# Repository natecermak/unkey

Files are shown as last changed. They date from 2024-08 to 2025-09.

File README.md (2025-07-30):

# Acoustic Underwater Text-based Communication Device (Name TBD)

## Purpose/Motivation
Divers often need to communicate with one another or with a dive boat, but typically can only communicate when in visual range of each other. A simple means to communicate with a bandwidth of text messaging (~40 wpm) over distances of several hundred meters could potentially save lives when if other divers or the dive boat can be made aware of and respond to unexpected conditions/situations.

## Communication scheme overview
Acoustic communication is basically the only feasible scheme underwater, and hence has been the standard for underwater communication since at least the early 1900s. Electromagnetic signals penetrate very poorly underwater, so convential means of communication (cellular communication, radio/walkie-talkies, bluetooth, wifi) are not feasible. Optical signaling is sometimes feasible (e.g. with flashlights), but relies on line of sight and good water clarity, and has limited range due to scattering and absorption underwater. However, if one has ever heard dolphins or whales underwater, they can attest to the immense distances these signals can travel, greatly exceeding the distance one can see underwater.

Underwater environments (a) add a lot of noise and (b) distort signals due to reflections.

Here, we use a **FM/AM/OFDM** scheme to send bits.

## Subsystems:

### Keyboard
To get around difficulties with mechanical keys, we chose to use magnetic sensors and a magnet-bearing stylus. Underwater, mechanical keys have several failure modes:
 - They can break in such a way that allows water into the device, and
 - As one goes underwater, pressure increases, which eventually can press keys on its own, at which point buttons are stuck in the 'pressed' state, and basically useless.
We chose to use omnipolar Hall-effect switches, which have a digital output that changes from high to low when the magnetic flux through the device increases beyond some threshold. We rapidly read out every key's on/off state using an array of daisy-chained shift registers, an approach commonly used in other keyboards. When the user brings the magnet-tipped stylus near a sensor "key", the microcontroller can read the change in the Hall-effect switch output.

Users typically prefer some tactile feedback when they hit a key, and this system doesn't naturally provide that. As such, we experimented with adding a soft (low coercivity) magnetic material (1-2mm mild steel ball bearings) above the Hall-effect sensor, to provide a small pull-in magnetic force when the stylus is brought close to the key. This provides tacticle sensation to the user that they have actually touched a key. It's essential that this material is magnetizable so that it attracts the stylus, but also that it cannot develop a permanent magnetic moment. If it were to develop a permanent magnetic moment, it would turn the Hall-effect sensor on all the time and the key would be stuck "on".

Keyboard layout:
---------- Default, no modifier -------
1   2   3   4   5   6   7   8   9   0
q   w   e   r   t   y   u   i   o   p
  a   s   d   f   g   h   j   k   l   DEL
CAP z   x   c   v   b   n   m   ?   BCK
SYM      SPACESPACESPACESP   ,   .    RET
(plus 6 arrow keys, SEND)

---------- SYM modifier ---------------
!   @   #   $   %   ^   &   *   (   )
`   ~   -   _   =   +   :   ;   '   "
  [   ]   {   }   |   \   /   <   >   DEL
CAP z   x   c   v   b   n   m   ?   BCK
SYM      SPACESPACESPACESP   ,   .    RET

key count is:
    row 1: 10 keys
    row 2: 10 keys
    row 3: 10 keys
    row 4: 10 keys
    row 5: 5 keys
    off-grid: 6 arrow keys, 1 SEND key
Total: 52 keys

Non-character keys: 6 arrow keys, SEND, BCK, DEL, CAP, SYM

Future work could use open-drain hall-effect sensors in a grid to give more precise hit-boxes (e.g. a 2x2 grid of AH1925-HK4-7, wired in parallel, for each key). However, this would be significantly more expensive, as it would require roughly 4x as many switches.

### Microcontroller
We use a Teensy 4.1 microcontroller due to ease of development. Essential features this microcontroller provides are:
 - rapid (~100 ksps) ADC readout via DMA
 - SPI peripheral for driving a TFT LCD scree
n - DMA-compatible SPI peripheral for driving a DAC
 - I2C peripheral for controlling an external switch matrix
However, many other microcontrollers would likely work fine for this system.

### Battery
We use a rechargeable lithium ion battery, which provides a nominal 3.7V input.

### Transducer
We use a 45mm x 45mm x 1.4mm square piezo plate from Steminc (SMPL45W45T14111) as a transducer. This piezo is spec'd as having a capacitance of 5.4nF +- 20%. It's made from material SM111, which has a piezo d33 constant of 320e-12 C/N.

We made some measurements of the impedance at various frequencies:
    - Frequency   Real      Imaginary     (Capacitance, Q)
    -  0.1 kHz:   570    -  103.5k imag   (15.3nF, Q=182)
    -  1.0 kHz:    45    -   10.42k imag  (15.3nF, Q=236)
    - 10.0 kHz:     2.9  -    1.03k imag  (15.4nF, Q=356)
    - 40.0 kHz:     2.25 -       63 imag  (63.0nF, Q=28)
    -100.0 kHz:    -0.09 -      132 imag  (12nF,   Q=1350)

Overall, this seems pretty discrepant with their claim of 5.4nF. Given two parallel plates of this size, separated by 1.4mm, and a dielectric constant of 1400 (also from the [SM111 materials page](http://www.steminc.com/piezo/PZ_property.asp)), the calculated capacitance should be 17.9nF, closer to our measured value than their spec.

We also purchased several other transducers to try out, but have not yet used/characterized ther others:
- SMD25T14F15111 - Piezo Ceramic Disc 25x1.4mm R 1.5 Mhz          1.9 nF
- SMD50T21F1000R - Piezo Electric Disc 50x2.1mm R 1 MHz           10 nF

### Transducer driver

### Transducer sensor
We use a charge amplifier circuit with a configurable gain.

### Sensor data processing
We use Goertzel filters to extract amplitude and phase at a fixed set of frequencies.

### Screen
TBD.

### Enclosure
TBD.

## Version history:
v1.2 PCB changes:
 - [X] switch from teensy 4.1 to t4 for space
 - [X] add battery monitor circuitry
 - [X] replicate LiIon charger circuit on it https://github.com/adafruit/Adafruit-USB-LiIon-LiPoly-Charger-PCB/tree/master
 - [X] switch shift registers to qfn
 - [X] redo keyboard layout
 - [X] add 40-pin ZIF connector for 3.2" TFT from buydisplay.com
 - [X] make all passives 0402 for consistency
 - [X] add explicit space for screen
 - [X] add explicit space for battery
 - [X] add explicit space for Qi charger coil + PCB
 - [X] pull LAT down on MCP4, or just wire it out -- cant leave it floating
 - [X] CE on 5V boost wont work! needs to be always enabled, and drive a switch
 - [X] figure out FMARK and RD on ZIF connector for display: tested with them floating and display still works, so non-essential

v1.3 pcb
 - [X] split board into two separate parts with explicit design for overall assembly. This is for two reasons:
    1. so that I can do single-sided assembly on both pieces, but then have some parts sticking up (keyboard) and some facing down (teensy/driver electronics)
    2. it makes the face of the screen flush with the face of the magnetic switches.
 - [X] fix TFT connector pin numbering (it's backwards from the connector)
 - [X] make an attempt at a BOM

---

## Firmware File Organization

```
firmware/
├── platformio.ini
├── include/                  # All header files
│   ├── battery.h
│   ├── chat_logic.h
│   ├── comm.h
│   ├── config.h              # Shared constants, types, UI/chat/layout settings
│   ├── display.h
│   ├── goertzel.h
│   ├── hardware_config.h     # Pin assignments and hardware setup
│   └── keyboard.h
├── src/                      # Main firmware source code
│   ├── battery.cpp
│   ├── chat_logic.cpp        # Message buffer, scrolling, state management
│   ├── comm.cpp              # Encode/decode bits, tx/rx state
│   ├── display.cpp           # Drawing chat, keyboard, cursor
│   ├── goertzel.cpp          # Frequency detection (demodulation)
│   ├── keyboard.cpp          # Polling, key states, modifiers, stylus interaction
│   └── main.cpp              # Entry point: setup(), loop(), high-level orchestration
├── test/                     # Unit test suites (organized by feature and file)
│   ├── receiving/
│   │   ├── test_adc_buffer_full_interrupt/
│   │   │   └── adc_buffer_full_interrupt.cpp
│   │   ├── test_decode_single_bit_from_adc_window/
│   │   │   └── decode_single_bit_from_adc_window.cpp
│   │   ├── test_deliver_message/
│   │   │   └── deliver_message.cpp
│   │   ├── test_get_bit_from_top_frequency/
│   │   │   └── get_bit_from_top_frequency.cpp
│   │   ├── test_parse_message/
│   │   │   └── parse_message.cpp
│   ├── transmitting/
│   │   └── test_packetize_message/
│   │       └── packetize_message.cpp
│   ├── mock_display.cpp
│   └── mock_display.h
```

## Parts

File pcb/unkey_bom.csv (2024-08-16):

# | Reference | Qty | Value | Footprint | DNP | Digikey PN | URL
1 | C1, C2, C3, C4, C5, C6, C7, C10, C11, C20, C22, C23, C24, C26, C27, C31 | 16 | 0.1u | Capacitor_SMD:C_0402_1005Metric |  | 1276-1043-1-ND | https://www.digikey.com/en/products/detail/samsung-electro-mechanics/CL05A104KA5NNNC/3886701
2 | C8, C9, C21, C25, C28, C29, C32 | 7 | 2.2u | Capacitor_SMD:C_0402_1005Metric |  | 445-9028-1-ND | https://www.digikey.com/en/products/detail/tdk-corporation/C1005X5R1V225K050BC/3648550
3 | C12 | 1 | 33n | Capacitor_SMD:C_0402_1005Metric
4 | C13 | 1 | 10n | Capacitor_SMD:C_0402_1005Metric
5 | C14 | 1 | 3.3n | Capacitor_SMD:C_0402_1005Metric
6 | C15 | 1 | 1n | Capacitor_SMD:C_0402_1005Metric
7 | C16 | 1 | 330p | Capacitor_SMD:C_0402_1005Metric
8 | C17 | 1 | 100p | Capacitor_SMD:C_0402_1005Metric
9 | C18 | 1 | 33p | Capacitor_SMD:C_0402_1005Metric
10 | C19 | 1 | 10p | Capacitor_SMD:C_0402_1005Metric
11 | D65, D66, D67 | 3 | LED | LED_SMD:LED_0603_1608Metric |  | APT1608CGCK | https://www.digikey.com/en/products/detail/kingbright/APT1608CGCK/1747514
12 | J1, J4, J7, J8, J11 | 5 | Conn_01x02_Pin | Connector_PinHeader_2.54mm:PinHeader_1x02_P2.54mm_Vertical
13 | J2, J3 | 2 | Conn_01x05_Pin | Connector_PinHeader_2.54mm:PinHeader_1x05_P2.54mm_Vertical
14 | J6 | 1 | Conn_01x40_Pin | Connector_FFC-FPC:Hirose_FH12-40S-0.5SH_1x40-1MP_P0.50mm_Horizontal |  | https://www.digikey.com/en/products/detail/hirose-electric-co-ltd/FH12A-40S-0-5SH-55/1110338 | https://www.digikey.com/en/products/detail/hirose-electric-co-ltd/FH12A-40S-0-5SH-55/1110338
15 | J12, J13, J14 | 3 | Conn_01x02_Pin | Connector_PinHeader_2.54mm:PinHeader_1x02_P2.54mm_Vertical | DNP
16 | PS1 | 1 | PDSE1-S3-D24-M | unkey-footprints:CONV_PDSE1-S3-D24-M |  | 102-PDSE1-S3-D24-M-ND | https://www.digikey.com/en/products/detail/cui-inc/PDSE1-S3-D24-M/20526618
17 | R1, R79 | 2 | 100 | Resistor_SMD:R_0402_1005Metric
18 | R2, R3, R9, R81, R82, R84 | 6 | 1k | Resistor_SMD:R_0402_1005Metric
19 | R4 | 1 | 0 | Resistor_SMD:R_0402_1005Metric
20 | R5 | 1 | 100M | Resistor_SMD:R_0402_1005Metric |  | HMC0402JT100MCT-ND | https://www.digikey.com/en/products/detail/stackpole-electronics-inc/HMC0402JT100M/2683706
21 | R6, R80 | 2 | 500 | Resistor_SMD:R_0402_1005Metric
22 | R10 | 1 | 18k | Resistor_SMD:R_0402_1005Metric
23 | R11, R68 | 2 | 10k | Resistor_SMD:R_0402_1005Metric
24 | R76, R78 | 2 | 100k | Resistor_SMD:R_0402_1005Metric
25 | R83 | 1 | 2k | Resistor_SMD:R_0402_1005Metric
26 | TH1 | 1 | 10k | Resistor_SMD:R_0402_1005Metric |  | 490-NCU15XH103F6SRCCT-ND | https://www.digikey.com/en/products/detail/murata-electronics/NCU15XH103F6SRC/10702829
27 | U1, U2, U3, U4, U5, U6, U7, U8, U9, U10, U11, U12, U13, U14, U15, U16, U17, U18, U19, U20, U21, U22, U23, U24, U25, U26, U27, U28, U29, U30, U31, U32, U33, U34, U35, U36, U37, U38, U39, U40, U41, U42, U43, U44, U46, U47, U48, U49, U50, U51, U52 | 51 | AH1912-W | Package_TO_SOT_SMD:SC-59 |  | AH1912-W-7DICT-ND | https://www.digikey.com/en/products/detail/diodes-incorporated/AH1912-W-7/10071170
28 | U45, U68, U69, U70 | 4 | AH1921-W-7 | Package_TO_SOT_SMD:SC-59 |  | AH1921-W-7DICT-ND | https://www.digikey.com/en/products/detail/diodes-incorporated/AH1921-W-7/9674238
29 | U53, U54, U55, U56, U57, U58, U59 | 7 | SN74LV165ARGYR | Package_DFN_QFN:Texas_RGY_R-PVQFN-N16_EP2.05x2.55mm |  | 296-13937-1-ND | https://www.digikey.com/en/products/detail/texas-instruments/SN74LV165ARGYR/521496
30 | U60 | 1 | MYRBP500080B21RE | unkey-footprints:MYRBP500080B21RE |  | 811-MYRBP500080B21RECT-ND | https://www.digikey.com/en/products/detail/murata-power-solutions-inc/myrbp500080b21re/18679061
31 | U61 | 1 | 2342-05-000 | unkey-footprints:2342-05-000 |  | 306-1111-ND | https://www.digikey.com/en/products/detail/coto-technology/2342-05-000/388948
32 | U62, U65 | 2 | TLV9062xD | Package_SO:SOIC-8_3.9x4.9mm_P1.27mm |  | 296-47857-1-ND | https://www.digikey.com/en/products/detail/texas-instruments/TLV9062IDR/7364940
33 | U63 | 1 | ADG728 | Package_SO:TSSOP-16_4.4x5mm_P0.65mm |  | 505-ADG728BRUZ-REEL7CT-ND | https://www.digikey.com/en/products/detail/analog-devices-inc/ADG728BRUZ-REEL7/995093
34 | U64 | 1 | MCP48CVD21 | Package_DFN_QFN:DFN-10-1EP_3x3mm_P0.5mm_EP1.55x2.48mm |  | 150-MCP48CVD21T-E/MFCT-ND | https://www.digikey.com/en/products/detail/microchip-technology/MCP48CVD21T-E-MF/16709741
35 | U66 | 1 | XC6210B332MR | Package_TO_SOT_SMD:SOT-23-5 |  | 893-1075-1-ND | https://www.digikey.com/en/products/detail/torex-semiconductor-ltd/XC6210B332MR-G/2138119
36 | U67 | 1 | ADA4098 | Package_TO_SOT_SMD:SOT-23-6 |  | 505-ADA4098-1BUJZ-RL7CT-ND | https://www.digikey.com/en/products/detail/analog-devices-inc/ADA4098-1BUJZ-RL7/15194948
37 | U71, U73 | 2 | CPC1002N | Package_SO:SOP-4_3.8x4.1mm_P2.54mm |  | CLA221-ND | https://www.digikey.com/en/products/detail/ixys-integrated-circuits-division/CPC1002N/1025047
38 | U76 | 1 | Teensy4.0 | unkey-footprints:Teensy40 |  | DEV-16997 | https://www.digikey.com/en/products/detail/sparkfun-electronics/DEV-16997/13158150
39 | U80 | 1 | MCP73833 | Package_DFN_QFN:DFN-10-1EP_3x3mm_P0.5mm_EP1.58x2.35mm |  | MCP73833T-AMI/MFCT-ND | https://www.digikey.com/en/products/detail/microchip-technology/MCP73833T-AMI-MF/1223181

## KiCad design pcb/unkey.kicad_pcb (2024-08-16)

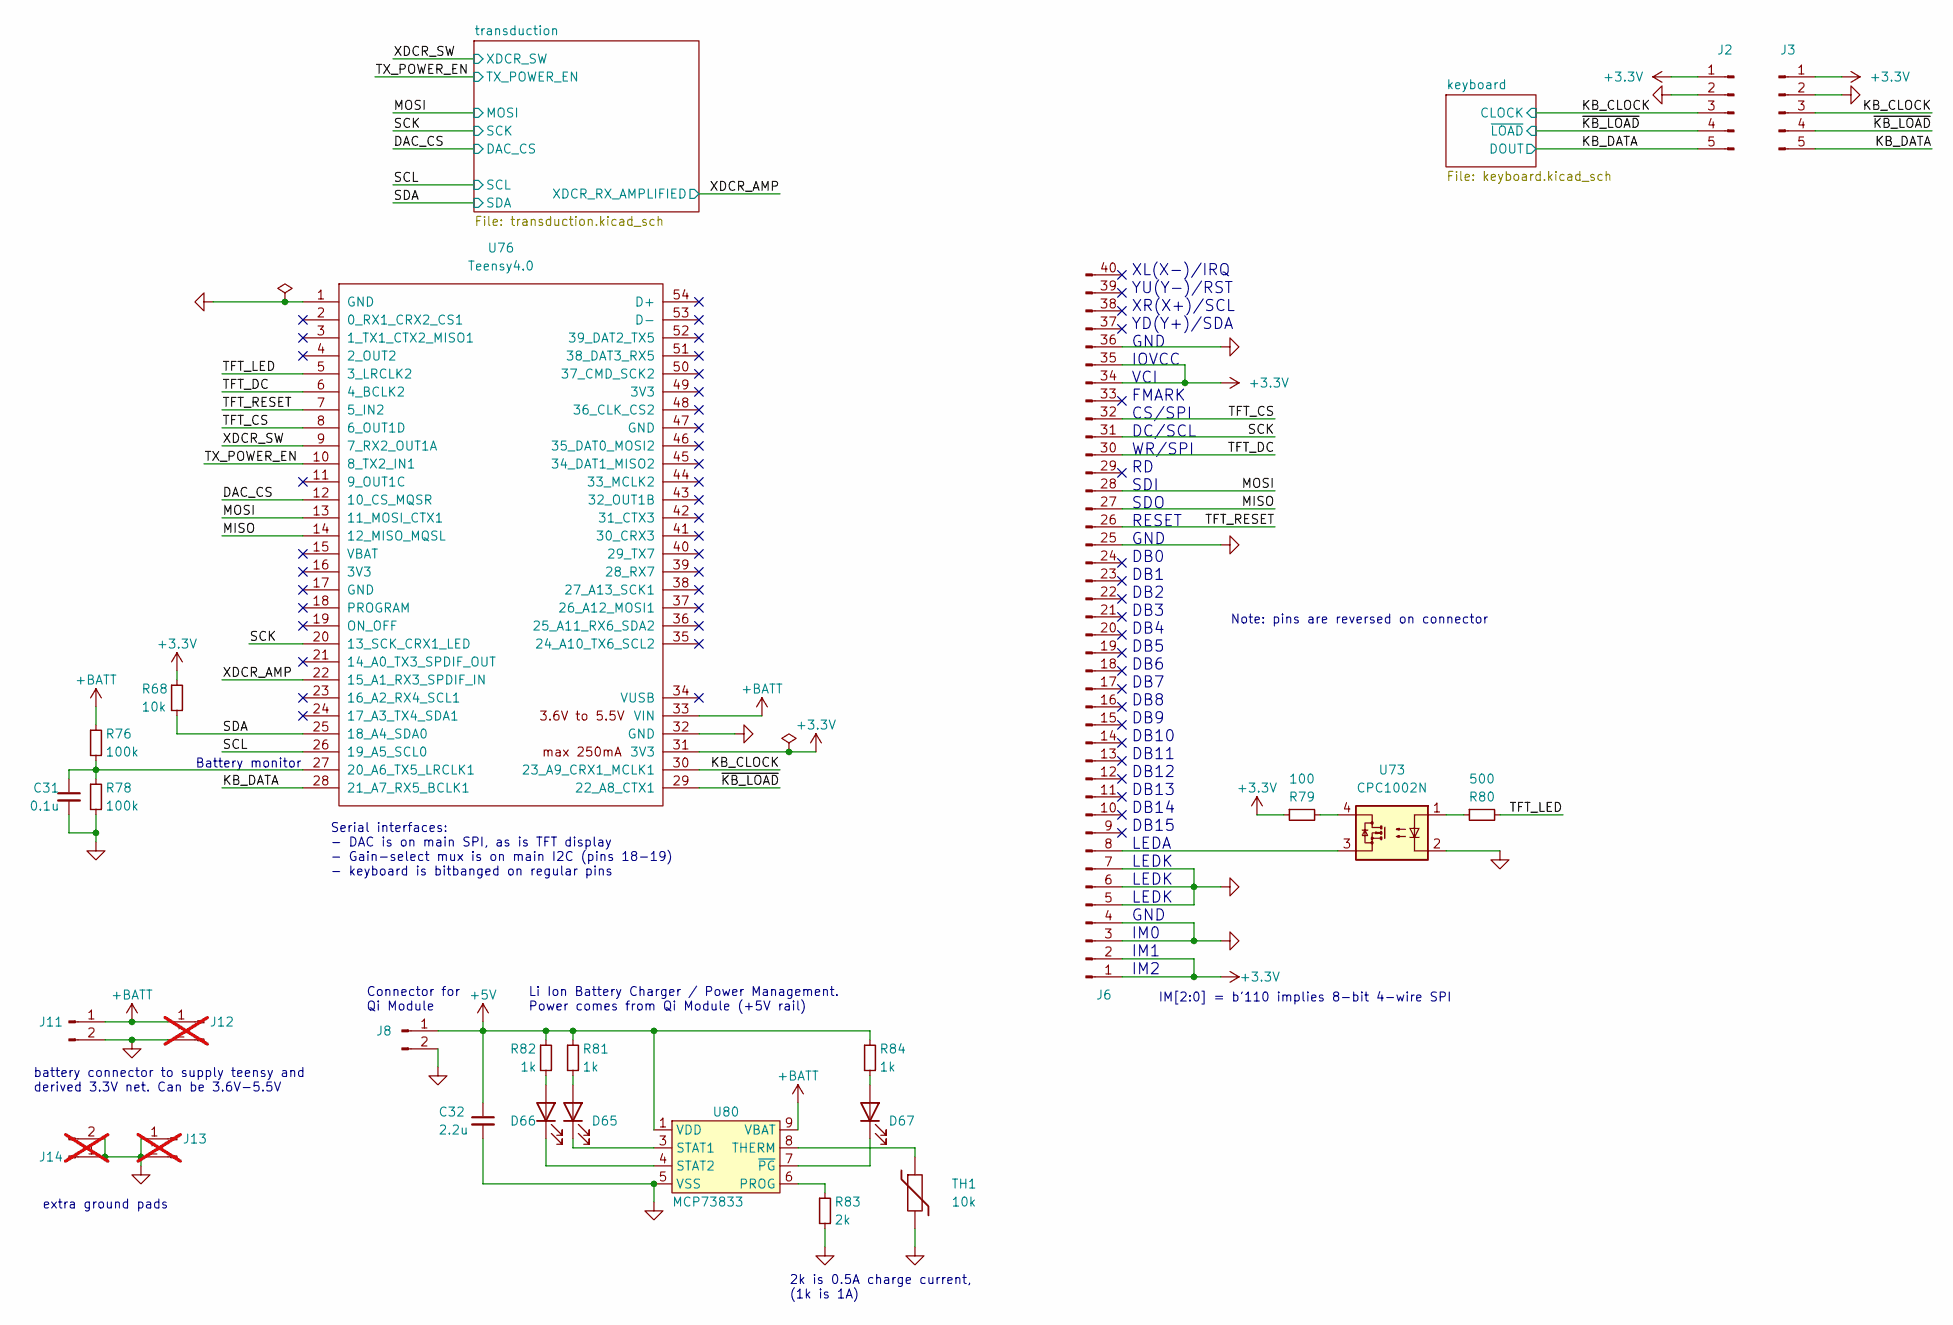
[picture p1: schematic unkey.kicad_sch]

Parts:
C31: 0.1u; C_0402_1005Metric; MPN CL05A104KA5NNNC; Digikey PN 1276-1043-1-ND
C32: 2.2u; C_0402_1005Metric; MPN C1005X5R1V225K050BC; Digikey PN 445-9028-1-ND
D65, D66, D67: LED; LED_0603_1608Metric; MPN 754-1116-1-ND; Digikey PN APT1608CGCK
J2, J3: Conn_01x05_Pin; PinHeader_1x05_P2.54mm_Vertical
J6: Conn_01x40_Pin; Hirose_FH12-40S-0.5SH_1x40-1MP_P0.50mm_Horizontal; MPN FH12A-40S-0.5SH(55); Digikey PN HFK140CT-ND
J8, J11: Conn_01x02_Pin; PinHeader_1x02_P2.54mm_Vertical
J12, J13, J14: Conn_01x02_Pin; PinHeader_1x02_P2.54mm_Vertical; not fitted
R68: 10k; R_0402_1005Metric
R76, R78: 100k; R_0402_1005Metric
R79: 100; R_0402_1005Metric
R80: 500; R_0402_1005Metric
R81, R82, R84: 1k; R_0402_1005Metric
R83: 2k; R_0402_1005Metric
TH1: 10k; R_0402_1005Metric; MPN NCU15XH103F6SRC; Digikey PN 490-NCU15XH103F6SRCCT-ND
U73: CPC1002N; SOP-4_3.8x4.1mm_P2.54mm; MPN CPC1002N; Digikey PN CLA221-ND
U76: Teensy4.0; Teensy40; MPN TEENSY 4.0 (HEADERS); Digikey PN DEV-16997
U80: MCP73833; DFN-10-1EP_3x3mm_P0.5mm_EP1.58x2.35mm; MPN MCP73833T-AMI/MF; Digikey PN MCP73833T-AMI/MFCT-ND

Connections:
+3.3V: J2.1, J3.1, J6.1, J6.2, J6.34, J6.35, R68.1, R79.1, U76.31 (3V3); also elsewhere on the board
+5V: C32.1, J8.1, R81.1, R82.1, R84.1, U80.1 (VDD), U80.2 (VDD)
+BATT: J11.1, J12.1, R76.1, U76.33 (VIN), U80.9 (VBAT), U80.10 (VBAT); also elsewhere on the board
/DAC_CS: U76.12 (10_CS_MQSR); also elsewhere on the board
/KB_CLOCK: J2.3, J3.3, U76.30 (23_A9_CRX1_MCLK1); also elsewhere on the board
/KB_DATA: J2.5, J3.5, U76.28 (21_A7_RX5_BCLK1); also elsewhere on the board
/MISO: J6.27, U76.14 (12_MISO_MQSL)
/MOSI: J6.28, U76.13 (11_MOSI_CTX1); also elsewhere on the board
/SCK: J6.31, U76.20 (13_SCK_CRX1_LED); also elsewhere on the board
/SCL: U76.26 (19_A5_SCL0); also elsewhere on the board
/SDA: R68.2, U76.25 (18_A4_SDA0); also elsewhere on the board
/TFT_CS: J6.32, U76.8 (6_OUT1D)
/TFT_DC: J6.30, U76.6 (4_BCLK2)
/TFT_LED: R80.2, U76.5 (3_LRCLK2)
/TFT_RESET: J6.26, U76.7 (5_IN2)
/TX_POWER_EN: U76.10 (8_TX2_IN1); also elsewhere on the board
/XDCR_AMP: U76.22 (15_A1_RX3_SPDIF_IN); also elsewhere on the board
/XDCR_SW: U76.9 (7_RX2_OUT1A); also elsewhere on the board
/~KB_LOAD: J2.4, J3.4, U76.29 (22_A8_CTX1); also elsewhere on the board
GND: C31.2, C32.2, J2.2, J3.2, J6.3, J6.4, J6.5, J6.6, J6.7, J6.25, J6.36, J8.2, J11.2, J12.2, J13.1, J13.2, J14.1, J14.2, R78.2, R83.2, TH1.2, U73.2, U76.1 (GND), U76.32 (GND), U80.5 (VSS), U80.11 (EP); also elsewhere on the board
unnamed: D65.2 (A), R81.2
unnamed: D65.1 (K), U80.3 (STAT1)
unnamed: D66.2 (A), R82.2
unnamed: D66.1 (K), U80.4 (STAT2)
unnamed: D67.2 (A), R84.2
unnamed: D67.1 (K), U80.7 (~PG)
unnamed: J6.8, U73.3
unnamed: R79.2, U73.4
unnamed: R80.1, U73.1
unnamed: C31.1, R76.2, R78.1, U76.27 (20_A6_TX5_LRCLK1)
unnamed: R83.1, U80.6 (PROG)
unnamed: TH1.1, U80.8 (THERM)

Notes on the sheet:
extra ground pads
2k is 0.5A charge current, (1k is 1A)
Note: pins are reversed on connector
XL(X-)/IRQ YU(Y-)/RST XR(X+)/SCL YD(Y+)/SDA GND IOVCC VCI FMARK CS/SPI DC/SCL WR/SPI RD SDI SDO RESET GND DB0 DB1 DB2 DB3 DB4 DB5 DB6 DB7 DB8 DB9 DB10 DB11 DB12 DB13 DB14 DB15 LEDA LEDK LEDK LEDK GND IM0 IM1 IM2
Li Ion Battery Charger / Power Management. Power comes from Qi Module (+5V rail)
IM[2:0] = b'110 implies 8-bit 4-wire SPI
Battery monitor
Connector for Qi Module
battery connector to supply teensy and derived 3.3V net. Can be 3.6V-5.5V
Serial interfaces: - DAC is on main SPI, as is TFT display - Gain-select mux is on main I2C (pins 18-19) - keyboard is bitbanged on regular pins

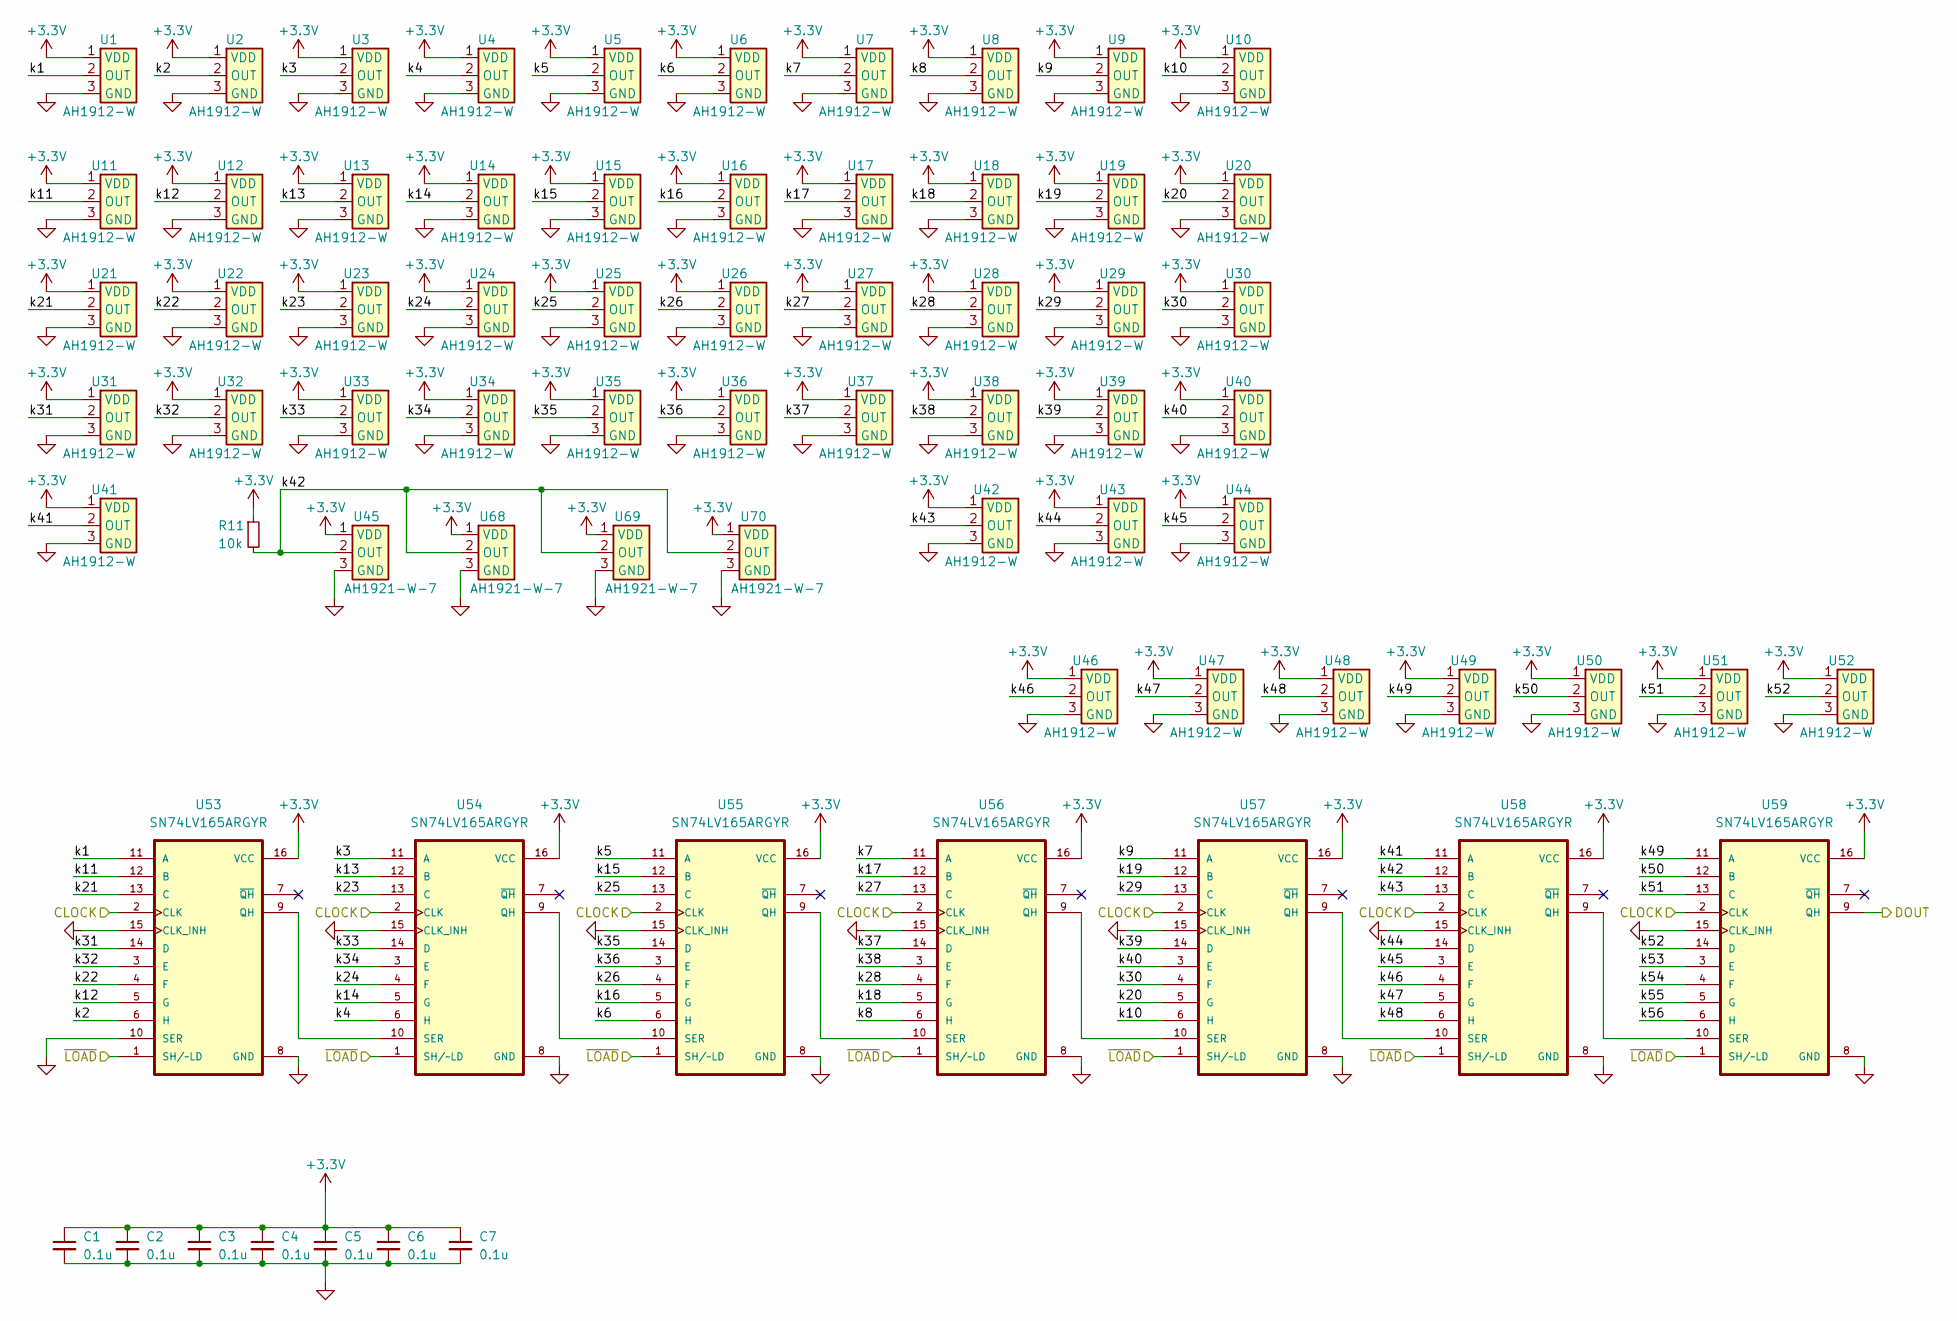
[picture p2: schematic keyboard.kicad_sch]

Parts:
C1, C2, C3, C4, C5, C6, C7: 0.1u; C_0402_1005Metric; MPN CL05A104KA5NNNC; Digikey PN 1276-1043-1-ND
R11: 10k; R_0402_1005Metric
U1, U2, U3, U4, U5, U6, U7, U8, U9, U10, U11, U12, U13, U14, U15, U16, U17, U18, U19, U20, U21, U22, U23, U24, U25, U26, U27, U28, U29, U30, U31, U32, U33, U34, U35, U36, U37, U38, U39, U40, U41, U42, U43, U44, U46, U47, U48, U49, U50, U51, U52: AH1912-W; SC-59; MPN AH1912-W-7; Digikey PN AH1912-W-7DICT-ND
U45, U68, U69, U70: AH1921-W-7; SC-59; MPN AH1921-W-7; Digikey PN AH1921-W-7DICT-ND
U53, U54, U55, U56, U57, U58, U59: SN74LV165ARGYR; Texas_RGY_R-PVQFN-N16_EP2.05x2.55mm; MPN SN74LV165ARGYR; Digikey PN 296-13937-1-ND

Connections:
+3.3V: C1.1, C2.1, C3.1, C4.1, C5.1, C6.1, C7.1, R11.1, U1.1 (VDD), U2.1 (VDD), U3.1 (VDD), U4.1 (VDD), U5.1 (VDD), U6.1 (VDD), U7.1 (VDD), U8.1 (VDD), U9.1 (VDD), U10.1 (VDD), U11.1 (VDD), U12.1 (VDD), U13.1 (VDD), U14.1 (VDD), U15.1 (VDD), U16.1 (VDD), U17.1 (VDD), U18.1 (VDD), U19.1 (VDD), U20.1 (VDD), U21.1 (VDD), U22.1 (VDD), U23.1 (VDD), U24.1 (VDD), U25.1 (VDD), U26.1 (VDD), U27.1 (VDD), U28.1 (VDD), U29.1 (VDD), U30.1 (VDD), U31.1 (VDD), U32.1 (VDD), U33.1 (VDD), U34.1 (VDD), U35.1 (VDD), U36.1 (VDD), U37.1 (VDD), U38.1 (VDD), U39.1 (VDD), U40.1 (VDD), U41.1 (VDD), U42.1 (VDD), U43.1 (VDD), U44.1 (VDD), U45.1 (VDD), U46.1 (VDD), U47.1 (VDD), U48.1 (VDD), U49.1 (VDD), U50.1 (VDD), U51.1 (VDD), U52.1 (VDD), U53.16 (VCC), U54.16 (VCC), U55.16 (VCC), U56.16 (VCC), U57.16 (VCC), U58.16 (VCC), U59.16 (VCC), U68.1 (VDD), U69.1 (VDD), U70.1 (VDD); also elsewhere on the board
/KB_CLOCK: U53.2 (CLK), U54.2 (CLK), U55.2 (CLK), U56.2 (CLK), U57.2 (CLK), U58.2 (CLK), U59.2 (CLK); also elsewhere on the board
/KB_DATA: U59.9 (QH); also elsewhere on the board
/keyboard/k1: U1.2 (OUT), U53.11 (A)
/keyboard/k2: U2.2 (OUT), U53.6 (H)
/keyboard/k3: U3.2 (OUT), U54.11 (A)
/keyboard/k4: U4.2 (OUT), U54.6 (H)
/keyboard/k5: U5.2 (OUT), U55.11 (A)
/keyboard/k6: U6.2 (OUT), U55.6 (H)
/keyboard/k7: U7.2 (OUT), U56.11 (A)
/keyboard/k8: U8.2 (OUT), U56.6 (H)
/keyboard/k9: U9.2 (OUT), U57.11 (A)
/keyboard/k10: U10.2 (OUT), U57.6 (H)
/keyboard/k11: U11.2 (OUT), U53.12 (B)
/keyboard/k12: U12.2 (OUT), U53.5 (G)
/keyboard/k13: U13.2 (OUT), U54.12 (B)
/keyboard/k14: U14.2 (OUT), U54.5 (G)
/keyboard/k15: U15.2 (OUT), U55.12 (B)
/keyboard/k16: U16.2 (OUT), U55.5 (G)
/keyboard/k17: U17.2 (OUT), U56.12 (B)
/keyboard/k18: U18.2 (OUT), U56.5 (G)
/keyboard/k19: U19.2 (OUT), U57.12 (B)
/keyboard/k20: U20.2 (OUT), U57.5 (G)
/keyboard/k21: U21.2 (OUT), U53.13 (C)
/keyboard/k22: U22.2 (OUT), U53.4 (F)
/keyboard/k23: U23.2 (OUT), U54.13 (C)
/keyboard/k24: U24.2 (OUT), U54.4 (F)
/keyboard/k25: U25.2 (OUT), U55.13 (C)
/keyboard/k26: U26.2 (OUT), U55.4 (F)
/keyboard/k27: U27.2 (OUT), U56.13 (C)
/keyboard/k28: U28.2 (OUT), U56.4 (F)
/keyboard/k29: U29.2 (OUT), U57.13 (C)
/keyboard/k30: U30.2 (OUT), U57.4 (F)
/keyboard/k31: U31.2 (OUT), U53.14 (D)
/keyboard/k32: U32.2 (OUT), U53.3 (E)
/keyboard/k33: U33.2 (OUT), U54.14 (D)
/keyboard/k34: U34.2 (OUT), U54.3 (E)
/keyboard/k35: U35.2 (OUT), U55.14 (D)
/keyboard/k36: U36.2 (OUT), U55.3 (E)
/keyboard/k37: U37.2 (OUT), U56.14 (D)
/keyboard/k38: U38.2 (OUT), U56.3 (E)
/keyboard/k39: U39.2 (OUT), U57.14 (D)
/keyboard/k40: U40.2 (OUT), U57.3 (E)
/keyboard/k41: U41.2 (OUT), U58.11 (A)
/keyboard/k42: R11.2, U45.2 (OUT), U58.12 (B), U68.2 (OUT), U69.2 (OUT), U70.2 (OUT)
/keyboard/k43: U42.2 (OUT), U58.13 (C)
/keyboard/k44: U43.2 (OUT), U58.14 (D)
/keyboard/k45: U44.2 (OUT), U58.3 (E)
/keyboard/k46: U46.2 (OUT), U58.4 (F)
/keyboard/k47: U47.2 (OUT), U58.5 (G)
/keyboard/k48: U48.2 (OUT), U58.6 (H)
/keyboard/k49: U49.2 (OUT), U59.11 (A)
/keyboard/k50: U50.2 (OUT), U59.12 (B)
/keyboard/k51: U51.2 (OUT), U59.13 (C)
/keyboard/k52: U52.2 (OUT), U59.14 (D)
/keyboard/k53: U59.3 (E)
/keyboard/k54: U59.4 (F)
/keyboard/k55: U59.5 (G)
/keyboard/k56: U59.6 (H)
/~KB_LOAD: U53.1 (SH/~LD), U54.1 (SH/~LD), U55.1 (SH/~LD), U56.1 (SH/~LD), U57.1 (SH/~LD), U58.1 (SH/~LD), U59.1 (SH/~LD); also elsewhere on the board
GND: C1.2, C2.2, C3.2, C4.2, C5.2, C6.2, C7.2, U1.3 (GND), U2.3 (GND), U3.3 (GND), U4.3 (GND), U5.3 (GND), U6.3 (GND), U7.3 (GND), U8.3 (GND), U9.3 (GND), U10.3 (GND), U11.3 (GND), U12.3 (GND), U13.3 (GND), U14.3 (GND), U15.3 (GND), U16.3 (GND), U17.3 (GND), U18.3 (GND), U19.3 (GND), U20.3 (GND), U21.3 (GND), U22.3 (GND), U23.3 (GND), U24.3 (GND), U25.3 (GND), U26.3 (GND), U27.3 (GND), U28.3 (GND), U29.3 (GND), U30.3 (GND), U31.3 (GND), U32.3 (GND), U33.3 (GND), U34.3 (GND), U35.3 (GND), U36.3 (GND), U37.3 (GND), U38.3 (GND), U39.3 (GND), U40.3 (GND), U41.3 (GND), U42.3 (GND), U43.3 (GND), U44.3 (GND), U45.3 (GND), U46.3 (GND), U47.3 (GND), U48.3 (GND), U49.3 (GND), U50.3 (GND), U51.3 (GND), U52.3 (GND), U53.8 (GND), U53.10 (SER), U53.15 (CLK_INH), U54.8 (GND), U54.15 (CLK_INH), U55.8 (GND), U55.15 (CLK_INH), U56.8 (GND), U56.15 (CLK_INH), U57.8 (GND), U57.15 (CLK_INH), U58.8 (GND), U58.15 (CLK_INH), U59.8 (GND), U59.15 (CLK_INH), U68.3 (GND), U69.3 (GND), U70.3 (GND); also elsewhere on the board
unnamed: U53.9 (QH), U54.10 (SER)
unnamed: U54.9 (QH), U55.10 (SER)
unnamed: U55.9 (QH), U56.10 (SER)
unnamed: U56.9 (QH), U57.10 (SER)
unnamed: U57.9 (QH), U58.10 (SER)
unnamed: U58.9 (QH), U59.10 (SER)

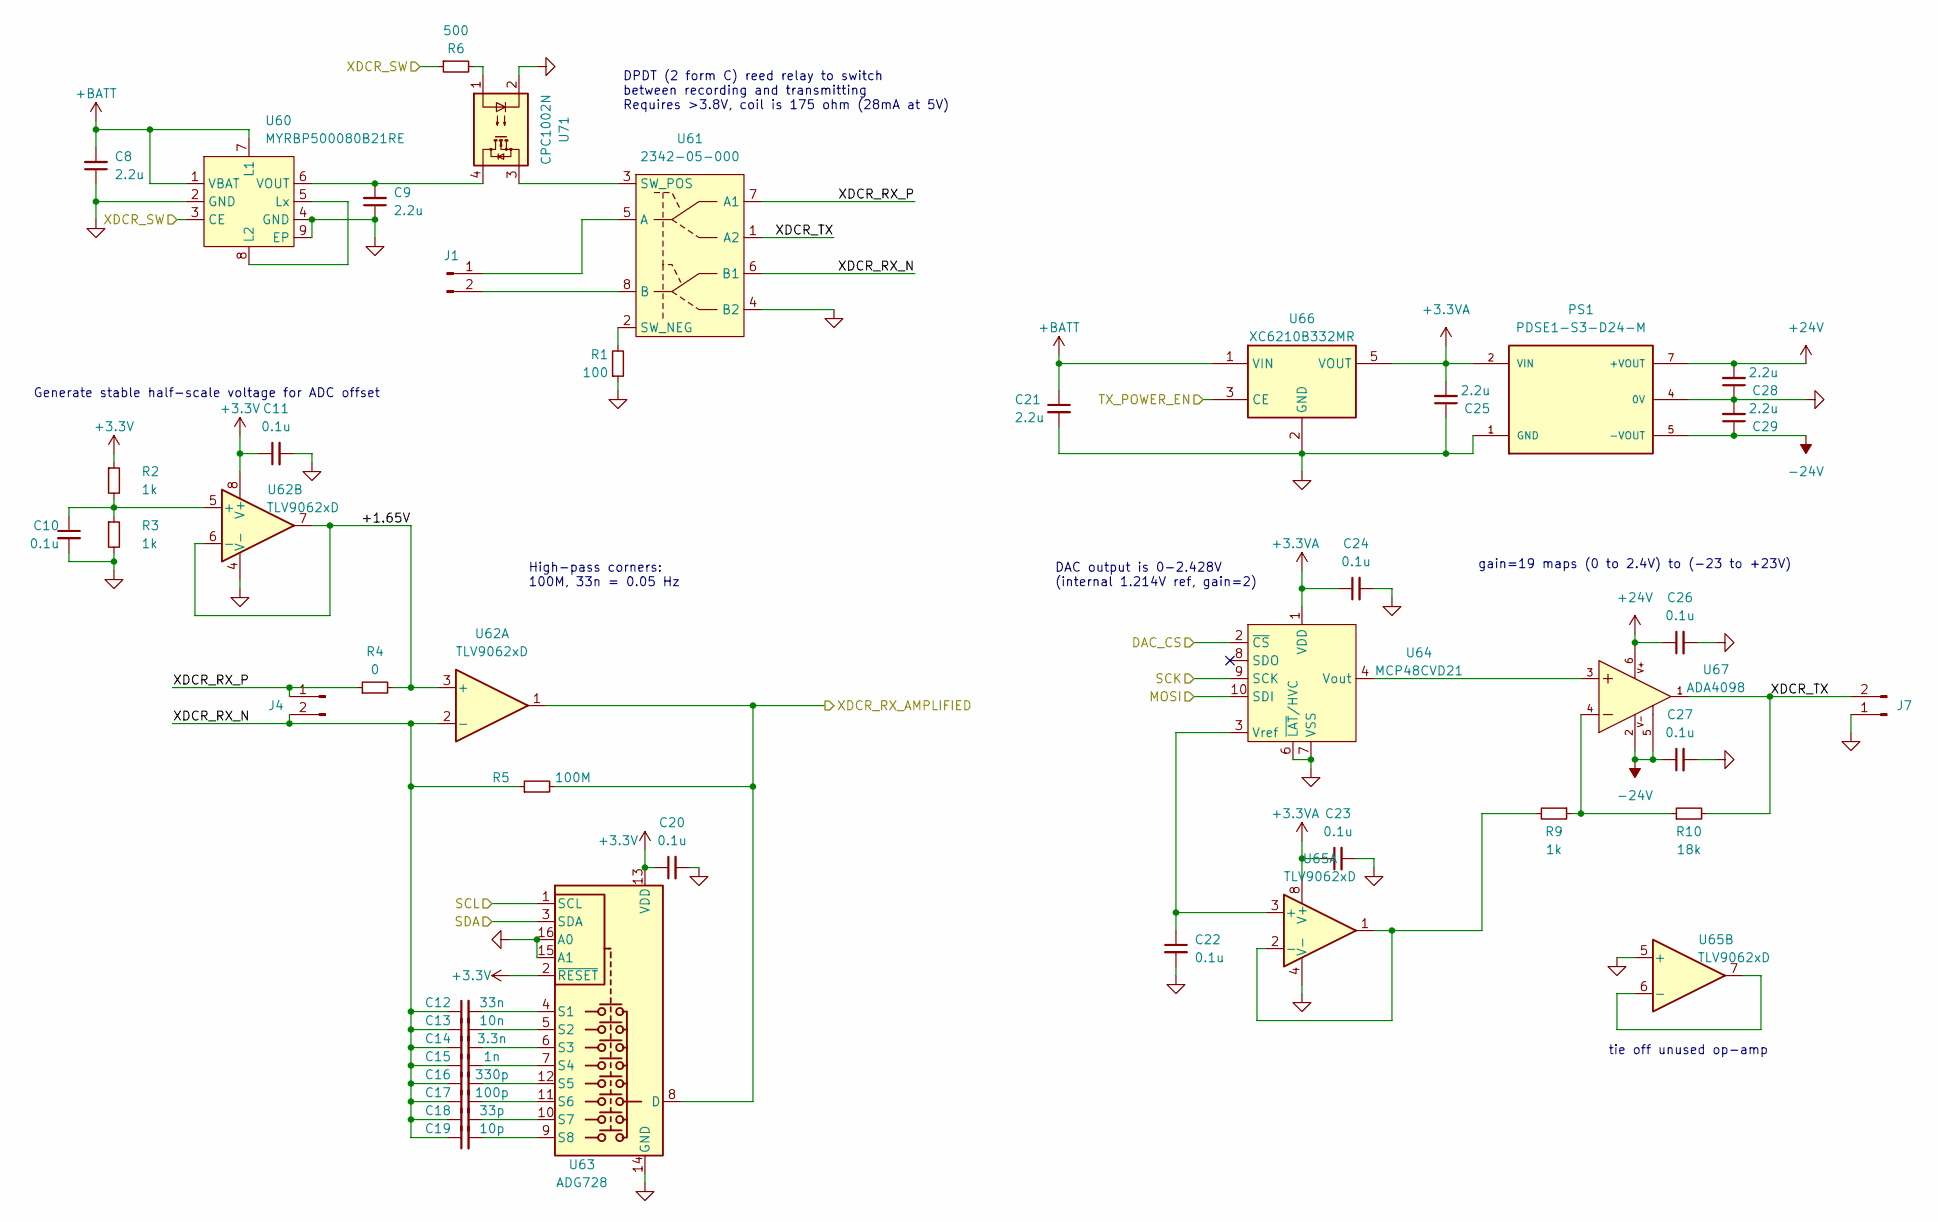
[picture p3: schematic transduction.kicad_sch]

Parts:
C8, C9, C21, C25, C28, C29: 2.2u; C_0402_1005Metric; MPN C1005X5R1V225K050BC; Digikey PN 445-9028-1-ND
C10, C11, C20, C22, C23, C24, C26, C27: 0.1u; C_0402_1005Metric; MPN CL05A104KA5NNNC; Digikey PN 1276-1043-1-ND
C12: 33n; C_0402_1005Metric
C13: 10n; C_0402_1005Metric
C14: 3.3n; C_0402_1005Metric
C15: 1n; C_0402_1005Metric
C16: 330p; C_0402_1005Metric
C17: 100p; C_0402_1005Metric
C18: 33p; C_0402_1005Metric
C19: 10p; C_0402_1005Metric
J1, J4, J7: Conn_01x02_Pin; PinHeader_1x02_P2.54mm_Vertical
PS1: PDSE1-S3-D24-M; CONV_PDSE1-S3-D24-M; PARTREV 1.0; Digikey PN 102-PDSE1-S3-D24-M-ND
R1: 100; R_0402_1005Metric
R2, R3, R9: 1k; R_0402_1005Metric
R4: 0; R_0402_1005Metric
R5: 100M; R_0402_1005Metric; MPN HMC0402JT100M; Digikey PN HMC0402JT100MCT-ND
R6: 500; R_0402_1005Metric
R10: 18k; R_0402_1005Metric
U60: MYRBP500080B21RE; MPN MYRBP500080B21RE; Digikey PN 811-MYRBP500080B21RECT-ND
U61: 2342-05-000; MPN 2342-05-000; Digikey PN 306-1111-ND
U62: TLV9062xD; SOIC-8_3.9x4.9mm_P1.27mm; MPN TLV9062IDR; Digikey PN 296-47857-1-ND
U63: ADG728; TSSOP-16_4.4x5mm_P0.65mm; MPN ADG728BRUZ-REEL7; Digikey PN 505-ADG728BRUZ-REEL7CT-ND
U64: MCP48CVD21; DFN-10-1EP_3x3mm_P0.5mm_EP1.55x2.48mm; MPN MCP48CVD21T-E/MF; Digikey PN 150-MCP48CVD21T-E/MFCT-ND
U65: TLV9062xD; SOIC-8_3.9x4.9mm_P1.27mm
U66: XC6210B332MR; SOT-23-5; MPN XC6210B332MR-G; Digikey PN 893-1075-1-ND
U67: ADA4098; SOT-23-6; PARTREV A; Digikey PN 505-ADA4098-1BUJZ-RL7CT-ND
U71: CPC1002N; SOP-4_3.8x4.1mm_P2.54mm; MPN CPC1002N; Digikey PN CLA221-ND

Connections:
+3.3V: C11.1, C20.1, R2.1, U62.8 (V+), U63.2 (~RESET), U63.13 (VDD); also elsewhere on the board
+3.3VA: C23.1, C24.1, C25.2, PS1.2 (VIN), U64.1 (VDD), U65.8 (V+), U66.5 (VOUT)
+24V: C26.1, C28.2, PS1.7 (+VOUT), U67.6
+BATT: C8.2, C21.1, U60.1 (VBAT), U60.7 (L1), U66.1 (VIN); also elsewhere on the board
-24V: C27.1, C29.1, PS1.5 (-VOUT), U67.2, U67.5
/DAC_CS: U64.2 (~CS); also elsewhere on the board
/MOSI: U64.10 (SDI); also elsewhere on the board
/SCK: U64.9 (SCK); also elsewhere on the board
/SCL: U63.1 (SCL); also elsewhere on the board
/SDA: U63.3 (SDA); also elsewhere on the board
/TX_POWER_EN: U66.3 (CE); also elsewhere on the board
/XDCR_AMP: R5.2, U62.1, U63.8 (D); also elsewhere on the board
/XDCR_SW: R6.1, U60.3 (CE); also elsewhere on the board
/transduction/+1.65V: R4.2, U62.3 (+), U62.6 (-), U62.7
/transduction/XDCR_RX_N: C12.1, C13.1, C14.1, C15.1, C16.1, C17.1, C18.1, C19.1, J4.2, R5.1, U61.6 (B1), U62.2 (-)
/transduction/XDCR_RX_P: J4.1, R4.1, U61.7 (A1)
/transduction/XDCR_TX: J7.2, R10.2, U61.1 (A2), U67.1
GND: C8.1, C9.1, C10.2, C11.2, C20.2, C21.2, C22.2, C23.2, C24.2, C25.1, C26.2, C27.2, C28.1, C29.2, J7.1, PS1.1 (GND), PS1.4 (0V), R1.1, R3.2, U60.2 (GND), U60.4 (GND), U60.9 (EP), U61.4 (B2), U62.4 (V-), U63.14 (GND), U63.15 (A1), U63.16 (A0), U64.6 (~LAT/HVC), U64.7 (VSS), U65.4 (V-), U65.5 (+), U66.2 (GND), U71.2; also elsewhere on the board
unnamed: J1.1, U61.5 (A)
unnamed: J1.2, U61.8 (B)
unnamed: R6.2, U71.1
unnamed: R9.1, R10.1, U67.4
unnamed: U60.5 (Lx), U60.8 (L2)
unnamed: C9.2, U60.6 (VOUT), U71.4
unnamed: R1.2, U61.2 (SW_NEG)
unnamed: U61.3 (SW_POS), U71.3
unnamed: C10.1, R2.2, R3.1, U62.5 (+)
unnamed: C12.2, U63.4 (S1)
unnamed: C13.2, U63.5 (S2)
unnamed: C14.2, U63.6 (S3)
unnamed: C15.2, U63.7 (S4)
unnamed: C16.2, U63.12 (S5)
unnamed: C17.2, U63.11 (S6)
unnamed: C18.2, U63.10 (S7)
unnamed: C19.2, U63.9 (S8)
unnamed: U64.4 (Vout), U67.3
unnamed: C22.1, U64.3 (Vref), U65.3 (+)
unnamed: R9.2, U65.1, U65.2 (-)
unnamed: U65.6 (-), U65.7

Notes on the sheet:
gain=19 maps (0 to 2.4V) to (-23 to +23V)
Generate stable half-scale voltage for ADC offset
High-pass corners: 100M, 33n = 0.05 Hz
tie off unused op-amp
DPDT (2 form C) reed relay to switch between recording and transmitting Requires >3.8V, coil is 175 ohm (28mA at 5V)
DAC output is 0-2.428V (internal 1.214V ref, gain=2)

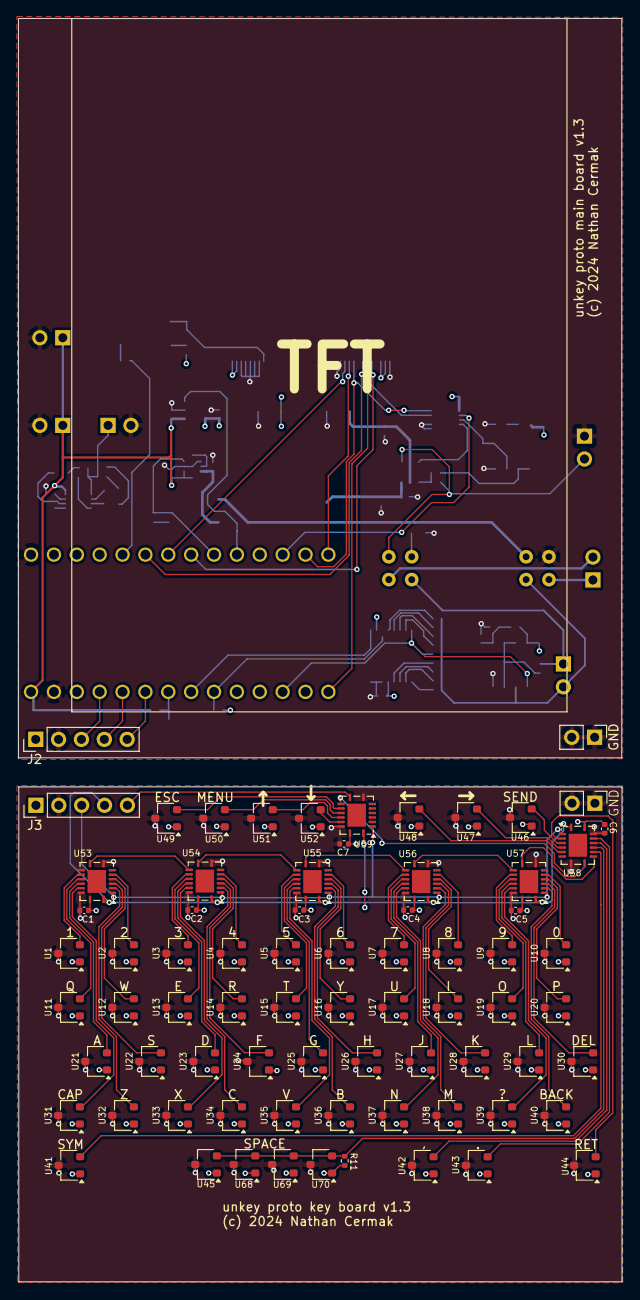
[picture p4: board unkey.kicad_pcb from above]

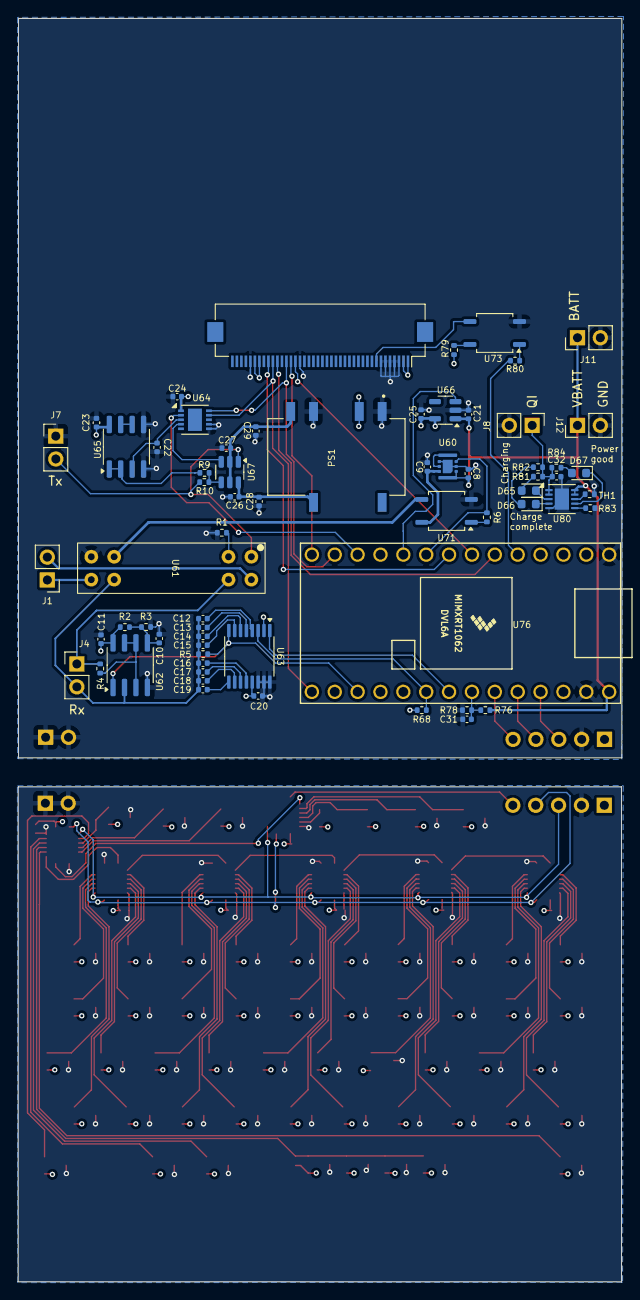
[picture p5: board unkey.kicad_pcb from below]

Board: 4 copper layers, 67.0 x 140.3 mm, 139 parts (65 on the bottom side), 118 nets.

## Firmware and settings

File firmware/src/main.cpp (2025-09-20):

// ==================================================================
// main.cpp
// Entry point: initializes all modules and runs main event loop
// ==================================================================
#include <SPI.h>
#include <Wire.h>

#include "battery.h"
#include "chat_logic.h"
#include "comm.h"
#include "config.h"
#include "display.h"
#include "goertzel.h"
#include "hardware_config.h"
#include "keyboard.h"

#ifndef UNIT_TEST

void setup() {
  Serial.begin(9600);
  // Checks if connection is working and waits up to 5 sec for it to happen:
  while (!Serial && millis() < 5000) ;
  delay(100);
  Serial.println("============================\nStarting setup()");

  // SPI commuincation bus for keyboard/display etc:
  SPI.begin();
  // I2C communication bus for charge amplifier:
  Wire.begin();
  // Specifies 12-bit resolution:
  analogReadResolution(12);

  // Testing purposes only:
  test_incoming_message.begin(incoming_message_callback, 1000000);

  // Module setup:
  setup_screen();
  setup_receiver();
  setup_transmitter();
  setup_keyboard_poller();

  Serial.println("setup() complete\n============================");
}

void loop() {
  // Runs once per bit analysis window (so every 5 ms, when get_bit_from_top_frequency() updates the magnitudes):
  if (mag_ready) {
    mag_ready = false;  // Clears the flag so we only print once
    Serial.println(curr_mag_2kHz + curr_mag_2_2kHz);
  }

  poll_battery();
}

#endif

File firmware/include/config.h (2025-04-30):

// ==================================================================
// config.h
// Declarations for central UI layout, messaging constants, and shared types
// ==================================================================
#ifndef CONFIG_H
#define CONFIG_H

#include <time.h>

//----------------------------------------
// Chat Display Configuration
//----------------------------------------
#define CHAT_BOX_LINE_PADDING       11      // Extra vertical space between chat lines
#define CHAT_BOX_START_X            0       // Chat box horizontal offset (0 is flush to left screen bound)
#define CHAT_BOX_START_Y            25      // Chat box vertical offset (0 is flush to top screen bound)
#define CHAT_BOX_WIDTH              235
#define CHAT_BOX_HEIGHT             201
#define CHAT_BOX_BOTTOM_PADDING     3
#define CHAT_WRAP_LIMIT             16      // Maximum characters per line before wrapping
#define LINE_HEIGHT                 10      // Height of each text line in pixels

//----------------------------------------
// Text and Buffer Parameters
//----------------------------------------
#define CHAR_WIDTH                  7       // Width of each character in pixels
#define MAX_CHAT_MESSAGES           50      // Maximum messages stored in chat history
#define MAX_NAME_LENGTH             20      // Maximum length for sender/recipient names
#define MAX_PACKET_SIZE             405     // Maximum packet size (including header/footer)
#define MAX_TEXT_LENGTH             400     // Maximum length of message text

//----------------------------------------
// Incoming/Outgoing Message Parameters
//----------------------------------------
#define INCOMING_TEXT_START_X       70      // Received message horizontal offset
#define INCOMING_BORDER_START_X     62
#define INCOMING_BORDER_WIDTH       132
#define INCOMING_BORDER_MARGIN      6
#define OUTGOING_TEXT_START_X       120
#define OUTGOING_BORDER_START_X     112
#define OUTGOING_BORDER_WIDTH       122

//----------------------------------------
// Keyboard and Typing Configuration
//----------------------------------------
#define SCAN_CHAIN_LENGTH           56      // Number of keys to poll per cycle
#define SEND_WRAP_LIMIT             30      // Wrap limit for outgoing messages
#define TEXT_SIZE                   1       // Text size multiplier (depends on display)
#define INCOMING_TIMESTAMP_START_X  10      // Horizontal offset for incoming timestamps
#define OUTGOING_TIMESTAMP_START_X  60      // Horizontal offset for outgoing timestamps
#define TYPING_BOX_START_X          0       // Typing box horizontal offset
#define TYPING_BOX_START_Y          225     // Typing box vertical offset
#define TYPING_BOX_HEIGHT           90      // Typing box height
#define TYPING_CURSOR_X             2       // Typing cursor horizontal offset
#define TYPING_CURSOR_Y             227     // Typing cursor vertical offset

//----------------------------------------
// Keyboard Key Indexes
//----------------------------------------
#define CAP_KEY_INDEX               3
#define SYM_KEY_INDEX               40
#define BACK_KEY_INDEX              36
#define DEL_KEY_INDEX               37
#define RET_KEY_INDEX               44
#define SEND_KEY_INDEX              45
#define ESC_KEY_INDEX               48
#define MENU_KEY_INDEX              49
#define LEFT_KEY_INDEX              47
#define UP_KEY_INDEX                50
#define DOWN_KEY_INDEX              51
#define RIGHT_KEY_INDEX             46
#define KEYBOARD_LAYOUT             "1qa~zsw23edxcfr45tgvbhy67ujnmki89ol?~~p0~ ,.\n           "
#define KEYBOARD_LAYOUT_SYM         "!@#$%^&*()`~-_=+:;\'\"[]{}|\\/<>~~zxcvbnm?~~ ,.\n           "

//----------------------------------------
// Battery and Display Spacing Configuration
//----------------------------------------
#define BATTERY_BOX_HEIGHT          10
#define SPACE_UNDER_BATTERY_WIDTH   15
#define BATTERY_BOX_WIDTH           80
#define SPACE_BESIDE_BATTERY_WIDTH  155     // Typically: CHAT_BOX_WIDTH - BATTERY_BOX_WIDTH
#define BORDER_PADDING_Y            6

//----------------------------------------
// Message and Test Constants
//----------------------------------------
#define RECIPIENT_UNKEY             "unkey"
#define RECIPIENT_VOID              "the void"
#define TEST_MESSAGE_TEXT           "Incoming from The Void"
#define TESTING_MESSAGE_COUNT_LIMIT 2

//----------------------------------------
// Type Definitions
//----------------------------------------
typedef struct {
  time_t timestamp;
  char sender[MAX_NAME_LENGTH];
  char recipient[MAX_NAME_LENGTH];
  char text[MAX_TEXT_LENGTH];
} message_t;

typedef struct _tx_parameters {
  float freq_low;
  float freq_high;
  uint32_t usec_per_bit;
} tx_parameters_t;

typedef struct {
  int message_buffer_write_index;
  int chat_history_message_count;
  int message_scroll_offset;  // Number of messages scrolled from most recent
  message_t chat_history[MAX_CHAT_MESSAGES];
} ChatBufferState;

#endif

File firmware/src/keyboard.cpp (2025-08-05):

// ==================================================================
// keyboard.cpp
// Handles keyboard scanning, polling, and input processing
// ==================================================================
#include <Arduino.h>

#include "chat_logic.h"
#include "comm.h"
#include "config.h"
#include "display.h"
#include "hardware_config.h"
#include "keyboard.h"

// ------------------------------------------------------------------
// State
// ------------------------------------------------------------------

extern bool screen_on;
extern char tx_display_buffer[];

static IntervalTimer keyboard_poller_timer;

// Will likely store the state of keys (??) - using a 64 bit integer
// => 64 key states, i.e. 1 for pressed, 0 for not:
static volatile uint64_t switch_state;

static const unsigned long screen_timeout_ms = 15000;

// Useful for debouncing/long presses:
static uint32_t time_of_last_press_ms;

// Runs poller at 100 Hz:
static const int keyboard_poller_period_usec = 1000;

// ------------------------------------------------------------------
// Functions
// ------------------------------------------------------------------

/**
 * Calculates the integer base-2 logarithm of x.
 * Returns the position of the highest set bit.
 */
static int ilog2(uint64_t x) {
  int i = 0;
  while (x) {
    x = x >> 1;
    i++;
  }
  return i;
}

/**
 * Reads the state of the keyboard by polling shift registers.
 * Detects new key presses, updates the screen, and processes
 * actions for CAPS, SYM, SEND, arrow keys, and printable keys.
 */
void poll_keyboard(ChatBufferState* state) {
  // static int modifier = 0;

  // Latches keyboard state into shift registers
  // kb_load_n_pin is an output pin which pulses a signal here from LOW to HIGH
  // low to hi transmission lets shift reg know to record keyboard state (8 bits per registr)
  digitalWrite(kb_load_n_pin, LOW);
  delayNanoseconds(5);
  digitalWrite(kb_load_n_pin, HIGH);
  delayNanoseconds(5);

  // Reads 64 bits of shift register, takes 2.63us, runs at 23 MHz
  // Note: bitbang to avoid taking up an SPI peripheral. Requires VERY little CPU time
  uint64_t read_buffer = 0;
  for (int bit = 0; bit < SCAN_CHAIN_LENGTH; bit++) {
    read_buffer |= (uint64_t)digitalReadFast(kb_data_pin) << ((SCAN_CHAIN_LENGTH - 1) - bit); // kb_data_pin is the state of each key press
    digitalWriteFast(kb_clock_pin, LOW);
    digitalWriteFast(kb_clock_pin, HIGH);
    delayNanoseconds(10);
  }
  digitalWriteFast(kb_clock_pin, LOW);

  // Compares results to previous one to detect new key presses
  uint64_t new_press = ~read_buffer & switch_state;
  switch_state = read_buffer;

  if (new_press) {
    time_of_last_press_ms = millis();

    if (!screen_on) {
      screen_on = true;
      digitalWrite(tft_led_pin, HIGH);
    } else {
      uint8_t key_index = ilog2(new_press) - 1;
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

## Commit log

2024-02-11 jeez this should have been in git a long time ago
    [unkey.kicad_pcb, unkey.kicad_sch]
2024-02-15 keyboard layout mostly done; not sure about remaining geometry -- screen connector remains big unknown, as does transducer driver/receiver circuitry
    [keyboard.kicad_sch, transduction.kicad_sch, unkey.kicad_pcb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]
2024-03-05 firmware: add setup for charge amplifier and transmitter switches/power supplies. Add datasheets for switch matrix, rename datasheet for shift register. Update README with correct keyboard layout.
    [firmware.ino]
2024-03-05 edits unclear, made weeks ago
    [keyboard.kicad_sch, unkey.kicad_pcb]
2024-03-05 DAC and 50V driver working
2024-03-21 PCB v1.2 ready to order
    [transduction.kicad_sch, unkey.kicad_pcb, unkey.kicad_sch]
2024-03-23 add v1.2 gerbers (which have backwards TFT connector pin numbering and hence TFT will be non-functional)
2024-03-24 start of splitting board into keyboard and everything else
    [unkey.kicad_pcb, unkey.kicad_sch]
2024-03-25 board split into keyboard and main part. readme updated. tft connector was backwards, now fixed
    [unkey.kicad_pcb, unkey.kicad_sch]
2024-03-25 move pcb stuff into its own top-level subfolder. Add gerber zips
    [keyboard.kicad_sch, transduction.kicad_sch, unkey.kicad_pcb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]
2024-04-17 add part metadata and derived BOM for most parts
    [keyboard.kicad_sch, transduction.kicad_sch, unkey.kicad_pcb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]
2024-06-25 checkpoint; fix pin numbers for v1.3, read battery voltage, and print it to the TFT
    [unkey.kicad_pcb]
2024-07-01 backspace working; send button plumbed except for actual sending and updating history window.
2024-10-19 Added a ton of comments for reference - will remove later. Added functionality to log staged message content when 'send' is pressed.
2024-10-21 Got rid of data structure to hold staged chars to send, not necessary for time being. Also fixed RET to not log a wonky 0
    [firmware.ino]
2024-11-19 Used a timer interrupt to simulate incoming messages and added handling to read and display those. Fixed a bug with chat wrapping and tweaked some other display things
    [firmware.ino]
2024-12-12 Refactoring display_chat_history and bug fix for oldest message getting cut from display - also changed scroll logic to scroll by messages instead of lines which seems less bug-prone
    [firmware.ino]
2024-12-12 Fixed line break logic
    [firmware.ino]
2025-02-27 Added logic to transmit bits as audible tones - currently just using a test message transmitted during setup
2025-03-18 Moved pin declarations out of main file
2025-03-24 Modularized some logic around chat and display drawing functionality. Also fixed poll_keyboard to use passed in state since it was pulling from a global var unnecessarily
    [chat_logic.cpp, keyboard.cpp]
2025-03-26 Cleaned up display header/implementation files and fixed some comments elsewhere
    [config.h, hardware_config.h]
2025-04-17 Moved battery logic into separate file and cleaned up includes
2025-04-17 Added pin suffix to all pin declarations
2025-04-17 Last refactoring tweak to resolve individual comments
    [keyboard.cpp]
2025-04-17 Removed function prototypes from header files that weren't being used by other files
2025-05-30 Updated README file structure schematic
2025-06-12 Renamed get_bit_from_top_frequency() - formally process_bit - and cleaned up/renamed parse_message - formally attempt_message_extract. Confirmed existing tests are still both passing and firmware upl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
    [comm.cpp]
2025-06-18 Basic test setup for adc_buffer_full_interrupt. This completes testing setup for all steps of the receiving logic slow. All tests currently passing
2025-06-18 Fixed some incomplete test logic in test_adc_buffer_full_interrupt
    [adc_buffer_full_interrupt.cpp]
2025-06-25 Renamed print_ctr to something that actually makes sense
2025-07-01 Added test cases to decode_single_bit_from_adc_window, refactored decode_single_bit_from_adc_window and fixed a logical error that was resetting the Goertzel state too early
    [comm.cpp, decode_single_bit_from_adc_window.cpp]
2025-07-05 Added comments/changed var names to clarify what's happening in setup_receiver and updated buffer_size to 410 to account for a 81.92 kHz sample rate and 5 ms bit period
2025-07-23 Refactored DMA buffer names for clarity and consistency. Added cache notes and finalized placement of adc_buffer_half_2 in RAM2 using DMAMEM
2025-07-23 Updated tests to use renamed DMA buffer accessors and added cache flush for RAM2 writes. Cleaned up comments and clarified setup logic.'
2025-08-05 Addressing inline TODOs - all tests currently passing
2025-08-05 Renaming variables related to adc buffer to be more reflective of their functionality/usage
2025-09-09 Refactored Goertzel buffer handling by removing unused ADC half/full buffers, adding circular history buffers, and clarifying variable names. Replaced ambiguous “lock/unlock” terminology with MAX_WEA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
    [adc_buffer_full_interrupt.cpp, comm.cpp, decode_single_bit_from_adc_window.cpp]
2025-09-16 Clean-up/added missing doc strings
    [comm.cpp]
2025-09-20 Added mag_ready flag to print magnitudes once per window for Splot plotting

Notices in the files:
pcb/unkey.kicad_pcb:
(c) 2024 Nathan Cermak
